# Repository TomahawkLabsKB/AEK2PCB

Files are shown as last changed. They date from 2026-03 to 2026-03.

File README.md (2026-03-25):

This is a work in progress.

This project intends to replace the orignal PCB of the Apple M3501 (Apple Extended Keyboard 2, AEK2) with a PCB powered by a Pimoroni PGA2040, which is an RP2040 breakboard board. The PGA2040 is no longer in production and not readily available for purchase.

Backstory:
I have always enjoyed the Apple M3501 and been a fan of Alps SKCM/L switches and wanted a functional way to have an AEK2 with every flavor of Alps SKCM/L I could collect. I wanted to manufacture and design as much of this project as I can. 

The main objectives of this project as as follows:

#1. Replace the original PCB with a new PCB with the following features:

  1. Native USB support
  2. Fit the M3501 case
  3. Connect to the original ADB port daughter board for USB passthrough
  4. Retain indicator LEDS and locking Capslock switch
  5. Easy access to the BOOTSEL and RESET switches for easy flashing

#2. Replace the original plate with a new aluminum plate with the following features:
  1. Fit the M3501 case using the original rubber "gaskets" on the bottom and the locking tab on top
  2. Fit original stabilizers
  3. Allow access for left and right USB breakout locations
  4. Include mounting holes on the top of the plate for future custom case mounting

Bill of Material:

| Part | Spec | Ref Numbers | Amount |
| :--- | :--- | :--- | :--- |
| Diode | 1N4148 | D1-104 | 104 |
| LED | 5mm Diffused | LED1-3 | 3 |
| LED Resistor | 1/4w 220R | R1-3 | 3 |
| USB breakout | JST XH 2.54mm 5-Pin | J1-2 | 2 |
| Polyfuse | 60R050XU | F1 | 1 |
| USB Protection | USBLC6-2SC6 | U2 | 1 |
| Reset/bootsel button | 6mm Momentary | S106-107 | 2 |
| Keyswitch | Alps SKCM\L | S1-105 | 105 |

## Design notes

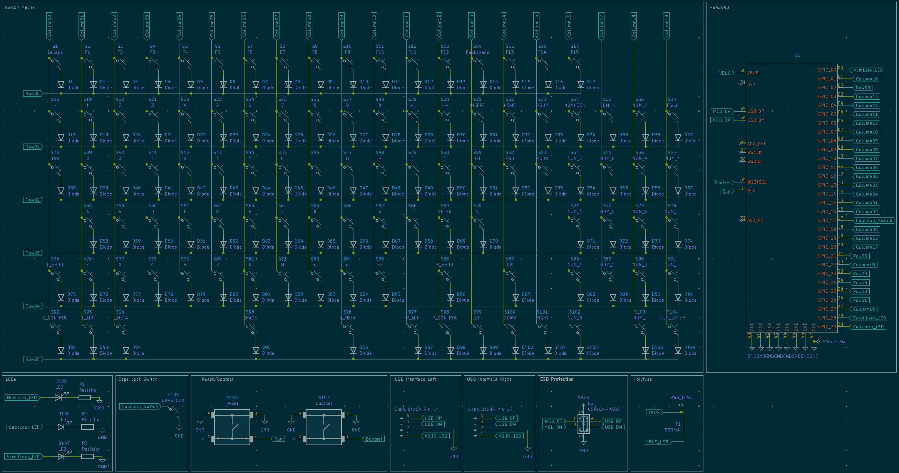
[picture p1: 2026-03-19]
Schematic_Editor.PNG

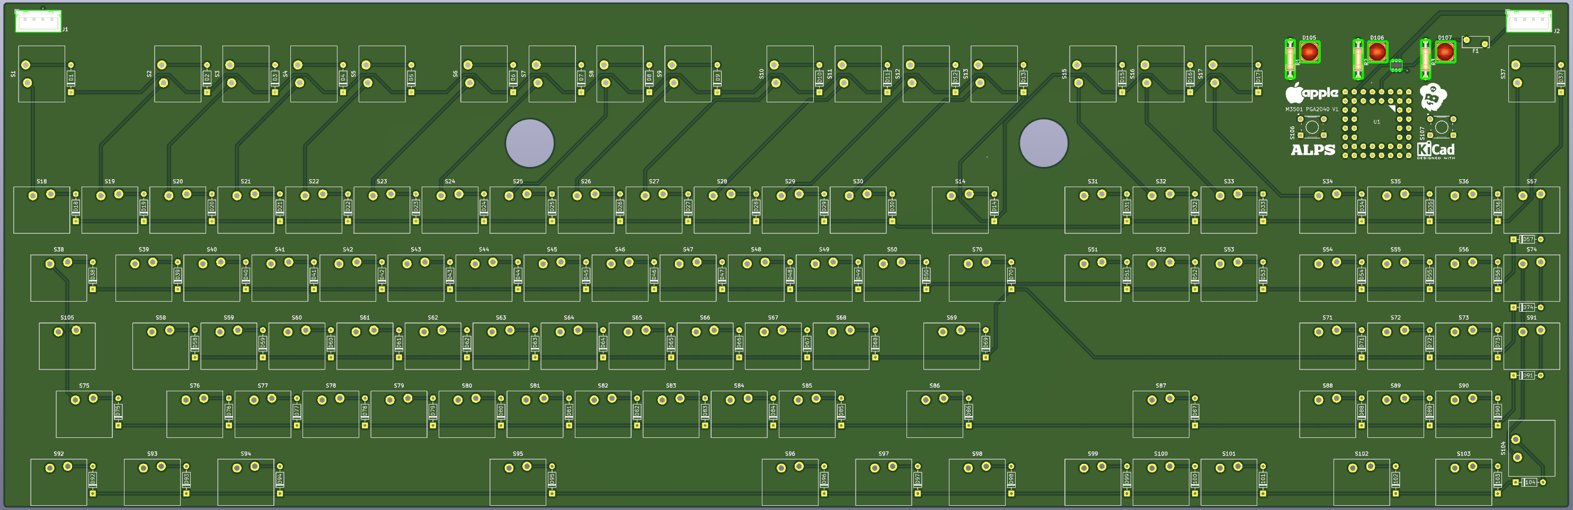
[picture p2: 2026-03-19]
3D_Viewer.PNG

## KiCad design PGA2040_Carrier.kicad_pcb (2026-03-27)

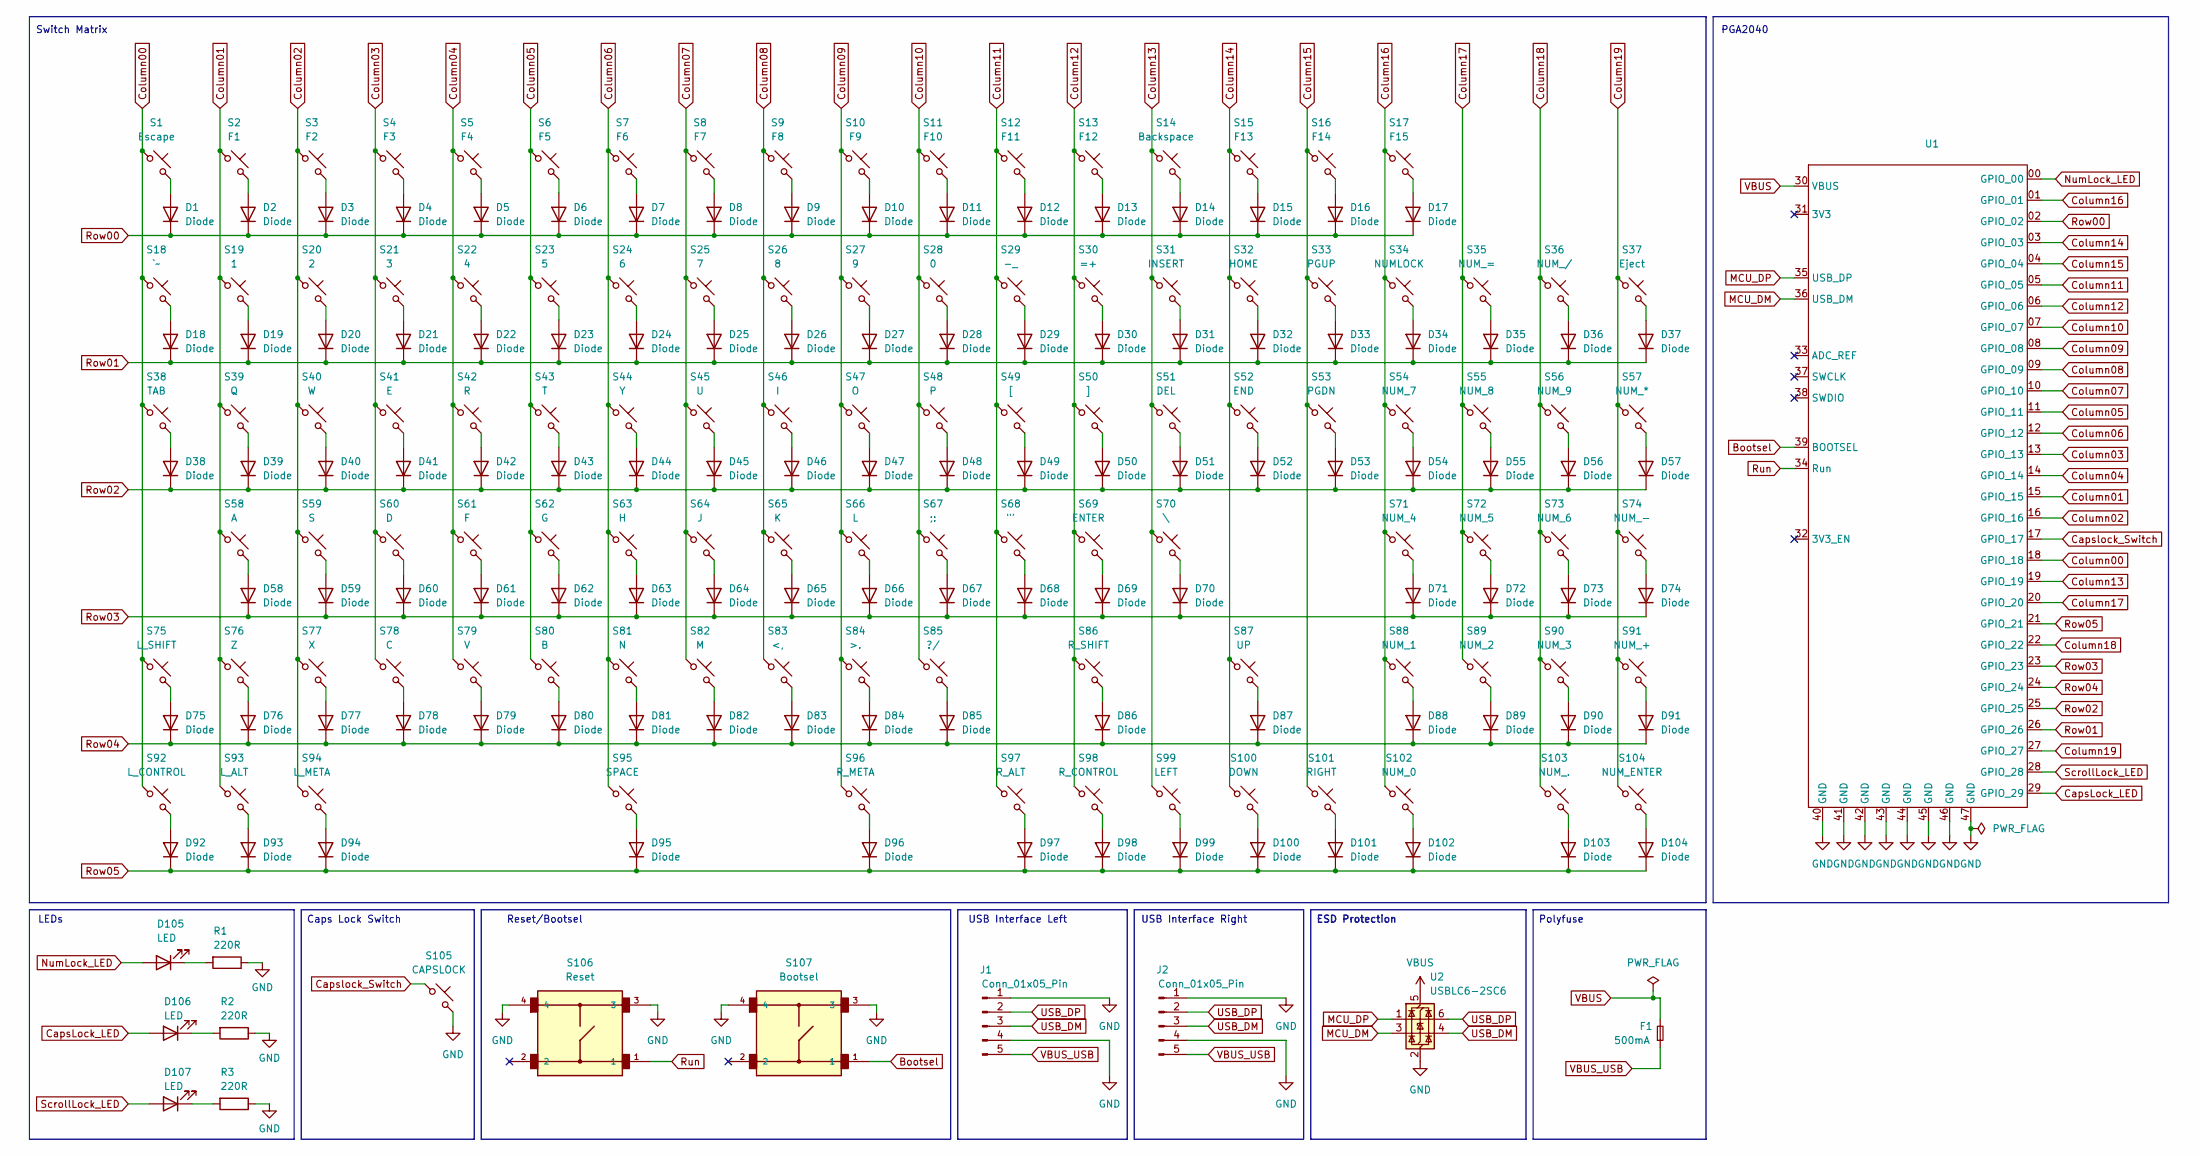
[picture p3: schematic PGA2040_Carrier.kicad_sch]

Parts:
D1, D2, D3, D4, D5, D6, D7, D8, D9, D10, D11, D12, D13, D14, D15, D16, D17, D18, D19, D20, D21, D22, D23, D24, D25, D26, D27, D28, D29, D30, D31, D32, D33, D34, D35, D36, D37, D38, D39, D40, D41, D42, D43, D44, D45, D46, D47, D48, D49, D50, D51, D52, D53, D54, D55, D56, D57, D58, D59, D60, D61, D62, D63, D64, D65, D66, D67, D68, D69, D70, D71, D72, D73, D74, D75, D76, D77, D78, D79, D80, D81, D82, D83, D84, D85, D86, D87, D88, D89, D90, D91, D92, D93, D94, D95, D96, D97, D98, D99, D100, D101, D102, D103, D104: Diode; THT Diode
D105, D106, D107: LED; LED_D5.0mm
F1: 500mA; Fuse_Bourns_MF-RHT050; LCSC C210357
J1, J2: Conn_01x05_Pin; PinHeader_1x05_P2.54mm_Vertical
R1, R2, R3: 220R; R_Axial_DIN0207_L6.3mm_D2.5mm_P10.16mm_Horizontal
S1: Escape; Alps_1.00u
S2: F1; Alps_1.00u
S3: F2; Alps_1.00u
S4: F3; Alps_1.00u
S5: F4; Alps_1.00u
S6: F5; Alps_1.00u
S7: F6; Alps_1.00u
S8: F7; Alps_1.00u
S9: F8; Alps_1.00u
S10: F9; Alps_1.00u
S11: F10; Alps_1.00u
S12: F11; Alps_1.00u
S13: F12; Alps_1.00u
S14: Backspace; Alps_2.00u
S15: F13; Alps_1.00u
S16: F14; Alps_1.00u
S17: F15; Alps_1.00u
S18: `~; Alps_1.00u
S19: 1; Alps_1.00u
S20: 2; Alps_1.00u
S21: 3; Alps_1.00u
S22: 4; Alps_1.00u
S23: 5; Alps_1.00u
S24: 6; Alps_1.00u
S25: 7; Alps_1.00u
S26: 8; Alps_1.00u
S27: 9; Alps_1.00u
S28: 0; Alps_1.00u
S29: -_; Alps_1.00u
S30: =+; Alps_1.00u
S31: INSERT; Alps_1.00u
S32: HOME; Alps_1.00u
S33: PGUP; Alps_1.00u
S34: NUMLOCK; Alps_1.00u
S35: NUM_=; Alps_1.00u
S36: NUM_/; Alps_1.00u
S37: Eject; Alps_1.00u
S38: TAB; Alps_1.50u
S39: Q; Alps_1.00u
S40: W; Alps_1.00u
S41: E; Alps_1.00u
S42: R; Alps_1.00u
S43: T; Alps_1.00u
S44: Y; Alps_1.00u
S45: U; Alps_1.00u
S46: I; Alps_1.00u
S47: O; Alps_1.00u
S48: P; Alps_1.00u
S49: [; Alps_1.00u
S50: ]; Alps_1.00u
S51: DEL; Alps_1.00u
S52: END; Alps_1.00u
S53: PGDN; Alps_1.00u
S54: NUM_7; Alps_1.00u
S55: NUM_8; Alps_1.00u
S56: NUM_9; Alps_1.00u
S57: NUM_*; Alps_1.00u
S58: A; Alps_1.00u
S59: S; Alps_1.00u
S60: D; Alps_1.00u
S61: F; Alps_1.00u
S62: G; Alps_1.00u
S63: H; Alps_1.00u
S64: J; Alps_1.00u
S65: K; Alps_1.00u
S66: L; Alps_1.00u
S67: ;:; Alps_1.00u
S68: "'; Alps_1.00u
S69: ENTER; Alps_2.25u
S70: \; Alps_1.50u
S71: NUM_4; Alps_1.00u
S72: NUM_5; Alps_1.00u
S73: NUM_6; Alps_1.00u
S74: NUM_-; Alps_1.00u
S75: L_SHIFT; Alps_2.25u
S76: Z; Alps_1.00u
S77: X; Alps_1.00u
S78: C; Alps_1.00u
S79: V; Alps_1.00u
S80: B; Alps_1.00u
S81: N; Alps_1.00u
S82: M; Alps_1.00u
S83: <,; Alps_1.00u
S84: >.; Alps_1.00u
S85: ?/; Alps_1.00u
S86: R_SHIFT; Alps_2.75u
S87: UP; Alps_1.00u
S88: NUM_1; Alps_1.00u
S89: NUM_2; Alps_1.00u
S90: NUM_3; Alps_1.00u
S91: NUM_+; Alps_1.00u
S92: L_CONTROL; Alps_1.50u
S93: L_ALT; Alps_1.25u
S94: L_META; Alps_1.50u
S95: SPACE; Alps_6.50u
S96: R_META; Alps_1.50u
S97: R_ALT; Alps_1.25u
S98: R_CONTROL; Alps_1.50u
S99: LEFT; Alps_1.00u
S100: DOWN; Alps_1.00u
S101: RIGHT; Alps_1.00u
S102: NUM_0; Alps_2.00u
S103: NUM_.; Alps_1.00u
S104: NUM_ENTER; Alps_2.00u
S105: CAPSLOCK; Alps_1.75u
S106: Reset; SW_B3F-1000
S107: Bootsel; SW_B3F-1000
U1: PGA2040
U2: USBLC6-2SC6; ESD_SOT-23-6; LCSC C2827654

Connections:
Bootsel: S107.1, U1.39 (BOOTSEL)
CapsLock_LED: D106.2 (A), U1.29 (GPIO_29)
Capslock_Switch: S105.1, U1.17 (GPIO_17)
Column00: S1.1, S18.1, S38.1, S75.1, S92.1, U1.18 (GPIO_18)
Column01: S2.1, S19.1, S39.1, S58.1, S76.1, S93.1, U1.15 (GPIO_15)
Column02: S3.1, S20.1, S40.1, S59.1, S77.1, S94.1, U1.16 (GPIO_16)
Column03: S4.1, S21.1, S41.1, S60.1, S78.1, U1.13 (GPIO_13)
Column04: S5.1, S22.1, S42.1, S61.1, S79.1, U1.14 (GPIO_14)
Column05: S6.1, S23.1, S43.1, S62.1, S80.1, U1.11 (GPIO_11)
Column06: S7.1, S24.1, S44.1, S63.1, S81.1, S95.1, U1.12 (GPIO_12)
Column07: S8.1, S25.1, S45.1, S64.1, S82.1, U1.10 (GPIO_10)
Column08: S9.1, S26.1, S46.1, S65.1, S83.1, U1.09 (GPIO_09)
Column09: S10.1, S27.1, S47.1, S66.1, S84.1, S96.1, U1.08 (GPIO_08)
Column10: S11.1, S28.1, S48.1, S67.1, S85.1, U1.07 (GPIO_07)
Column11: S12.1, S29.1, S49.1, S68.1, S97.1, U1.05 (GPIO_05)
Column12: S13.1, S30.1, S50.1, S69.1, S86.1, S98.1, U1.06 (GPIO_06)
Column13: S14.1, S31.1, S51.1, S70.1, S99.1, U1.19 (GPIO_19)
Column14: S15.1, S32.1, S52.1, S87.1, S100.1, U1.03 (GPIO_03)
Column15: S16.1, S33.1, S53.1, S101.1, U1.04 (GPIO_04)
Column16: S17.1, S34.1, S54.1, S71.1, S88.1, S102.1, U1.01 (GPIO_01)
Column17: S35.1, S55.1, S72.1, S89.1, U1.20 (GPIO_20)
Column18: S36.1, S56.1, S73.1, S90.1, S103.1, U1.22 (GPIO_22)
Column19: S37.1, S57.1, S74.1, S91.1, S104.1, U1.27 (GPIO_27)
GND: J1.1, J1.4, J2.1, J2.4, R1.1, R2.1, R3.1, S105.2, S106.3, S106.4, S107.3, S107.4, U1.40 (GND), U1.41 (GND), U1.42 (GND), U1.43 (GND), U1.44 (GND), U1.45 (GND), U1.46 (GND), U1.47 (GND), U2.2 (GND)
MCU_DM: U1.36 (USB_DM), U2.3 (I/O2)
MCU_DP: U1.35 (USB_DP), U2.1 (I/O1)
unnamed: D1.2 (A), S1.2
unnamed: D2.2 (A), S2.2
unnamed: D3.2 (A), S3.2
unnamed: D4.2 (A), S4.2
unnamed: D5.2 (A), S5.2
unnamed: D6.2 (A), S6.2
unnamed: D7.2 (A), S7.2
unnamed: D8.2 (A), S8.2
unnamed: D9.2 (A), S9.2
unnamed: D10.2 (A), S10.2
unnamed: D11.2 (A), S11.2
unnamed: D12.2 (A), S12.2
unnamed: D13.2 (A), S13.2
unnamed: D14.2 (A), S14.2
unnamed: D15.2 (A), S15.2
unnamed: D16.2 (A), S16.2
unnamed: D17.2 (A), S17.2
unnamed: D18.2 (A), S18.2
unnamed: D19.2 (A), S19.2
unnamed: D20.2 (A), S20.2
unnamed: D21.2 (A), S21.2
unnamed: D22.2 (A), S22.2
unnamed: D23.2 (A), S23.2
unnamed: D24.2 (A), S24.2
unnamed: D25.2 (A), S25.2
unnamed: D26.2 (A), S26.2
unnamed: D27.2 (A), S27.2
unnamed: D28.2 (A), S28.2
unnamed: D29.2 (A), S29.2
unnamed: D30.2 (A), S30.2
unnamed: D31.2 (A), S31.2
unnamed: D32.2 (A), S32.2
unnamed: D33.2 (A), S33.2
unnamed: D34.2 (A), S34.2
unnamed: D35.2 (A), S35.2
unnamed: D36.2 (A), S36.2
unnamed: D37.2 (A), S37.2
unnamed: D38.2 (A), S38.2
unnamed: D39.2 (A), S39.2
unnamed: D40.2 (A), S40.2
unnamed: D41.2 (A), S41.2
unnamed: D42.2 (A), S42.2
unnamed: D43.2 (A), S43.2
unnamed: D44.2 (A), S44.2
unnamed: D45.2 (A), S45.2
unnamed: D46.2 (A), S46.2
unnamed: D47.2 (A), S47.2
unnamed: D48.2 (A), S48.2
unnamed: D49.2 (A), S49.2
unnamed: D50.2 (A), S50.2
unnamed: D51.2 (A), S51.2
unnamed: D52.2 (A), S52.2
unnamed: D53.2 (A), S53.2
unnamed: D54.2 (A), S54.2
unnamed: D55.2 (A), S55.2
unnamed: D56.2 (A), S56.2
unnamed: D57.2 (A), S57.2
unnamed: D58.2 (A), S58.2
unnamed: D59.2 (A), S59.2
unnamed: D60.2 (A), S60.2
unnamed: D61.2 (A), S61.2
unnamed: D62.2 (A), S62.2
unnamed: D63.2 (A), S63.2
unnamed: D64.2 (A), S64.2
unnamed: D65.2 (A), S65.2
unnamed: D66.2 (A), S66.2
unnamed: D67.2 (A), S67.2
unnamed: D68.2 (A), S68.2
unnamed: D69.2 (A), S69.2
unnamed: D70.2 (A), S70.2
unnamed: D71.2 (A), S71.2
unnamed: D72.2 (A), S72.2
unnamed: D73.2 (A), S73.2
unnamed: D74.2 (A), S74.2
unnamed: D75.2 (A), S75.2
unnamed: D76.2 (A), S76.2
unnamed: D77.2 (A), S77.2
unnamed: D78.2 (A), S78.2
unnamed: D79.2 (A), S79.2
unnamed: D80.2 (A), S80.2
unnamed: D81.2 (A), S81.2
unnamed: D82.2 (A), S82.2
unnamed: D83.2 (A), S83.2
unnamed: D84.2 (A), S84.2
unnamed: D85.2 (A), S85.2
unnamed: D86.2 (A), S86.2
unnamed: D87.2 (A), S87.2
unnamed: D88.2 (A), S88.2
unnamed: D89.2 (A), S89.2
unnamed: D90.2 (A), S90.2
unnamed: D91.2 (A), S91.2
unnamed: D92.2 (A), S92.2
unnamed: D93.2 (A), S93.2
unnamed: D94.2 (A), S94.2
unnamed: D95.2 (A), S95.2
unnamed: D96.2 (A), S96.2
unnamed: D97.2 (A), S97.2
unnamed: D98.2 (A), S98.2
unnamed: D99.2 (A), S99.2
unnamed 125: D100.2 (A), S100.2; also elsewhere on the board
unnamed 126: D101.2 (A), S101.2; also elsewhere on the board
unnamed 127: D102.2 (A), S102.2; also elsewhere on the board
unnamed 128: D103.2 (A), S103.2; also elsewhere on the board
unnamed 129: D104.2 (A), S104.2; also elsewhere on the board
unnamed: D105.1 (K), R1.2
unnamed: D106.1 (K), R2.2
unnamed: D107.1 (K), R3.2
NumLock_LED: D105.2 (A), U1.00 (GPIO_00)
Row00: D1.1 (K), D2.1 (K), D3.1 (K), D4.1 (K), D5.1 (K), D6.1 (K), D7.1 (K), D8.1 (K), D9.1 (K), D10.1 (K), D11.1 (K), D12.1 (K), D13.1 (K), D14.1 (K), D15.1 (K), D16.1 (K), D17.1 (K), U1.02 (GPIO_02)
Row01: D18.1 (K), D19.1 (K), D20.1 (K), D21.1 (K), D22.1 (K), D23.1 (K), D24.1 (K), D25.1 (K), D26.1 (K), D27.1 (K), D28.1 (K), D29.1 (K), D30.1 (K), D31.1 (K), D32.1 (K), D33.1 (K), D34.1 (K), D35.1 (K), D36.1 (K), D37.1 (K), U1.26 (GPIO_26)
Row02: D38.1 (K), D39.1 (K), D40.1 (K), D41.1 (K), D42.1 (K), D43.1 (K), D44.1 (K), D45.1 (K), D46.1 (K), D47.1 (K), D48.1 (K), D49.1 (K), D50.1 (K), D51.1 (K), D52.1 (K), D53.1 (K), D54.1 (K), D55.1 (K), D56.1 (K), D57.1 (K), U1.25 (GPIO_25)
Row03: D58.1 (K), D59.1 (K), D60.1 (K), D61.1 (K), D62.1 (K), D63.1 (K), D64.1 (K), D65.1 (K), D66.1 (K), D67.1 (K), D68.1 (K), D69.1 (K), D70.1 (K), D71.1 (K), D72.1 (K), D73.1 (K), D74.1 (K), U1.23 (GPIO_23)
Row04: D75.1 (K), D76.1 (K), D77.1 (K), D78.1 (K), D79.1 (K), D80.1 (K), D81.1 (K), D82.1 (K), D83.1 (K), D84.1 (K), D85.1 (K), D86.1 (K), D87.1 (K), D88.1 (K), D89.1 (K), D90.1 (K), D91.1 (K), U1.24 (GPIO_24)
Row05: D92.1 (K), D93.1 (K), D94.1 (K), D95.1 (K), D96.1 (K), D97.1 (K), D98.1 (K), D99.1 (K), D100.1 (K), D101.1 (K), D102.1 (K), D103.1 (K), D104.1 (K), U1.21 (GPIO_21); also elsewhere on the board
Run: S106.1, U1.34 (Run)
ScrollLock_LED: D107.2 (A), U1.28 (GPIO_28)
USB_DM: J1.3, J2.3, U2.4 (I/O2)
USB_DP: J1.2, J2.2, U2.6 (I/O1)
VBUS: F1.2, U1.30 (VBUS), U2.5 (VBUS)
VBUS_USB: F1.1, J1.5, J2.5

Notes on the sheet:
USB Interface Left
Caps Lock Switch
USB Interface Right
Switch Matrix
Polyfuse
LEDs
PGA2040
ESD Protection
Reset/Bootsel

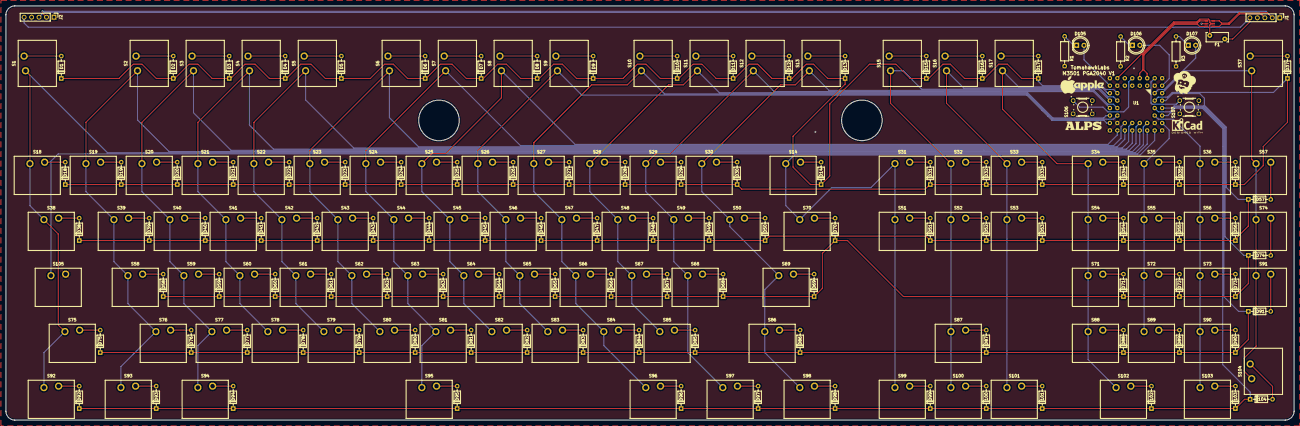
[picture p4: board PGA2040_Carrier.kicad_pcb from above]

Board: 2 copper layers, 438.3 x 140.9 mm, 222 parts (0 on the bottom side), 146 nets.

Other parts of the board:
100, 101, 102, 103, 104: Diode; THT Diode

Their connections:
unnamed 125: 100.2 (A); also elsewhere on the board
unnamed 126: 101.2 (A); also elsewhere on the board
unnamed 127: 102.2 (A); also elsewhere on the board
unnamed 128: 103.2 (A); also elsewhere on the board
unnamed 129: 104.2 (A); also elsewhere on the board
Row05: 100.1 (K), 101.1 (K), 102.1 (K), 103.1 (K), 104.1 (K); also elsewhere on the board
